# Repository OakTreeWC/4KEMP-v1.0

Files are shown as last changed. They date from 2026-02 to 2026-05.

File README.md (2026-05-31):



# 4KEMP v1.0

### 4 | the number four
### K | k
### E | ey
### M | macro
### P | pad

4KEMP really just a mini macro pad. Nothing special about it. Can be used to play music games and stuff.
This project was made to help my friend learn how to use KiCad and Fusion360, ~~but then became a [hackclub blueprint](https://blueprint.hackclub.com) project for me as well.~~
To use my project, one can use [vial](https://get.vial.today) to change what each key does, and then use it to run functions on their computer.





## Components


## PCB
pcbs are pretty kewl.
also you just lost the game lol.
### Top


### Bottom


## Soldering
I don't have any documentation from when I was actually doing it, but I do have pics of the final product.
### Top
IMG_2629cropped

### Bottom


A lot of my solder joints could be better, it is very inconsistent, and it doesn't look great, but I'm still happy with it.

## Case
I made a few mistakes, and since I neglected to even try to print it at home first, I let them slip, but whatever.

The upper case was 3d printed by JLC 3DP at my own expense in gray resin, which I honestly love the look and feel of. 

However, the lower case is where all the mistakes arose. Stupidity on my part caused these mistakes, but oh well. Because I added neopixels on the bottom and wanted to actually use them, I ordered my lower case in translucent resin. Unfortunately though, I didn't realize that this resin was super vulnerable to warping and had horrible dimensional accuracy. 

When I received the part, I quickly realized how bad it was. Therefore, I attempted to undo the warping with heat and pressure. I ended up pushing it too far though, resulting in a large crack in the base.

Additionally, the poor accuracy caused the top left corner of my macropad to be misaligned. It isn't too bad, but its definitely there.

### Issues

Thin case causing MASSIVE warping.



Attempt to fix warping causing large crack.



Excessive clearance around USB port.



Poor dimensional accuracy of lower case causing horrific misalignment.



## Assembly

Assembly was very straightforward. I first added threaded inserts into my lower case, then put my pcb into the upper case and installed all the switches. After that, I just put the entire upper case/pcb assembly into the lower case, tightened the three M3 bolts, and I was done.





## Bill of Materials
|Item |Description |Qty.|Unit Price (USD)|Total Price  (USD)|URL |Running Total (USD + Tax)|
|---|---|----|---|---|---|---|
|XIAO RP2040 |ARM® Cortex®-M0+ MCU 32-Bit Embedded Evaluation Board |1 |$4.68 |$4.68 |https://www.digikey.com/en/products/detail/seeed-technology-co-ltd/102010428/14672129 |$5.16 |
|Rotary Encoder |Rotary Encoder Incremental 24 Quadrature (Incremental) Horizontal |1 |$1.72 |$1.72 |https://www.digikey.com/en/products/detail/bourns-inc/PEC12R-4020F-S0024/4699271 |$7.06 |
|Reverse Neopixels |Addressable Lighting - 10 LED Discrete Red, Green, Blue (RGB) |1 |$2.95 |$2.95 |https://www.digikey.com/en/products/detail/adafruit-industries-llc/4960/14302512 |$10.31 |
|Backlight Neopixels |Addressable Lighting Neopixel 10 LED Discrete Serial (Shift Register) Red, Green, Blue (RGB) |1 |$4.50 |$4.50 |https://www.digikey.com/en/products/detail/adafruit-industries-llc/1655/5154679 |$15.27 |
|Akko Keyboard Switches|Akko V3 Silver Pro Keyboard Switch 5-Pin Linear Pre-Lubed Switches (45pcs) |1 |$16.99 |$16.99 |https://www.amazon.com/dp/B0CDW6W2P5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 |$34.00 |
|Schottky Diodes |Diode 30 V 200mA Surface Mount 0603 |4 |$0.17 |$0.68 |https://www.digikey.com/en/products/detail/taiwan-semiconductor-corporation/TSS54U-RGG/7360711 |$34.75 |
|Resistor |For Neopixel Data Line. 379 Ohms ±0.1% 0.1W, 1/10W Chip Resistor 0603 (1608 Metric) |1 |$0.12 |$0.12 |https://www.digikey.com/en/products/detail/koa-speer-electronics-inc/RN73R1JTTD3790B25/10016392 |$34.88 |
|PCB |PCB Manufactured by JLCPCB. White, 1.6mm, HASL w/ lead |5 |$0.40 |$2.00 |https://jlcpcb.com |$37.09 |
|Lower Case |Case Manufactured by JLC3DP. 8001 Resin, Translucent |1 |$2.19 |$2.19 |https://jlc3dp.com |$39.50 |
|Upper Case |Case Manufactured by JLCPCB. Black Resin |1 |$2.43 |$2.43 |https://jlc3dp.com |$42.18 |
|Keycaps |DSA Keycaps White 24pcs |1 |$8.99 |$8.99 |www.amazon.com/Mechkeeb-Profile-Switches-Keyboard-Replacement/dp/B0BWDTBF1L |$52.09 |
|Rotary Encoder Knob |Aluminum Rotary Encoder Knob 2pcs |1 |$8.99 |$8.99 |www.amazon.com/Szliyands-Aluminum-Electronic-Potentiometer-Knob，Switch/dp/B099PX52LW |$62.00 |
|Threaded Inserts |M3 Threaded Inserts 152pcs |1 |$6.99 |$6.99 |https://www.amazon.com/Vibit-Threaded-Soldering-Printing-Components/dp/B0FWWW8VP1/ref=sr_1_3 |$69.71 |
|Machine Screws |M3 Screw Kit |1 |$9.99 |$9.99 |https://www.amazon.com/Fgruh-750PCS-Assortment-Washers-Assorted/dp/B0FGV5FCBN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|$80.72 |
|Digikey Shipping | |1 |$4.99 |$4.99 | |$86.22 |
|JLC Shipping | |1 |$8.93 |$8.93 | |$96.07 |

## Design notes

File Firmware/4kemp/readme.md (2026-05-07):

# 4kemp

4kemp

*A short description of the keyboard/project*

* Keyboard Maintainer: [William C.](https://github.com/OakTreeWC)
* Hardware Supported: *The PCBs, controllers supported*
* Hardware Availability: *Links to where you can find this hardware*

Make example for this keyboard (after setting up your build environment):

    make 4kemp:default

Flashing example for this keyboard:

    make 4kemp:default:flash

See the [build environment setup](https://docs.qmk.fm/#/getting_started_build_tools) and the [make instructions](https://docs.qmk.fm/#/getting_started_make_guide) for more information. Brand new to QMK? Start with our [Complete Newbs Guide](https://docs.qmk.fm/#/newbs).

## Bootloader

Enter the bootloader in 3 ways:

* **Bootmagic reset**: Hold down the key at (0,0) in the matrix (usually the top left key or Escape) and plug in the keyboard
* **Physical reset button**: Briefly press the button on the back of the PCB - some may have pads you must short instead
* **Keycode in layout**: Press the key mapped to `QK_BOOT` if it is available

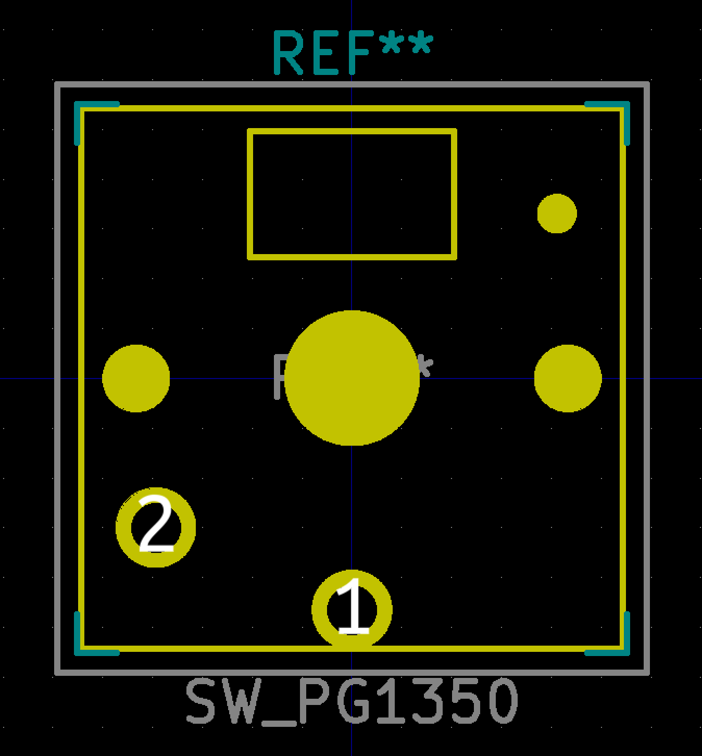
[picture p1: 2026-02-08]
KiCad/CAD Files/keyswitches.pretty-2.1/images/SW_PG1350.png

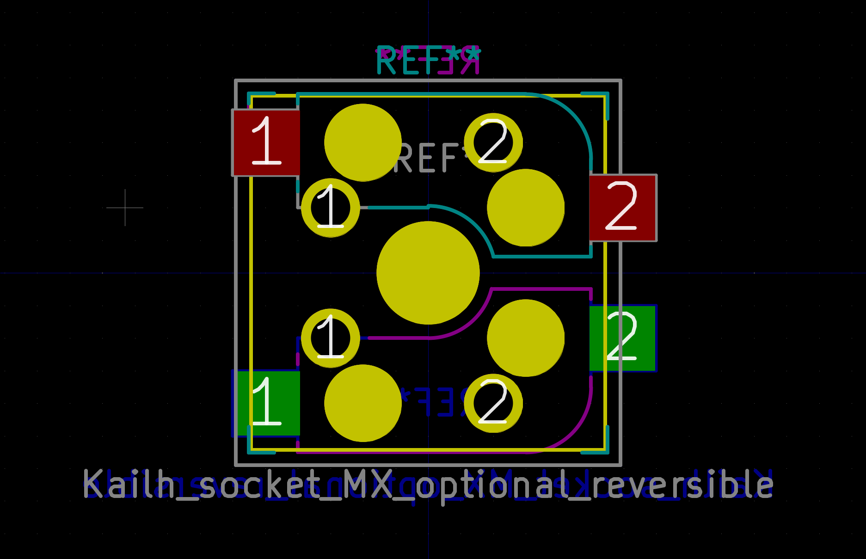
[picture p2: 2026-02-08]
KiCad/CAD Files/keyswitches.pretty-2.1/images/Kailh_socket_MX_optional_reversible_platemount.png

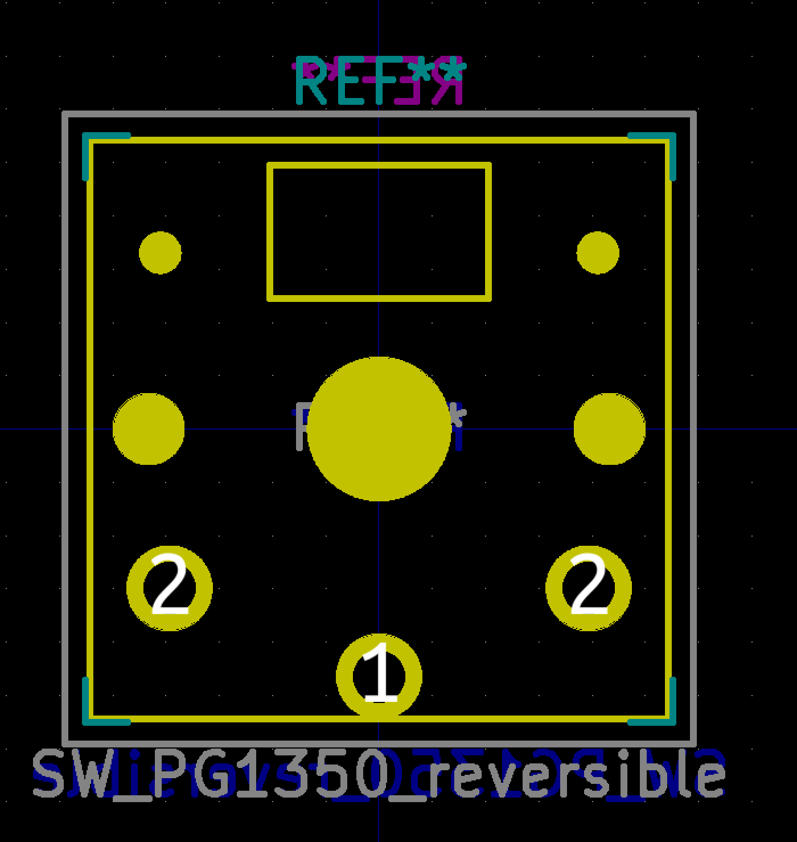
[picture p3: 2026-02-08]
KiCad/CAD Files/keyswitches.pretty-2.1/images/SW_PG1350_reversible.png

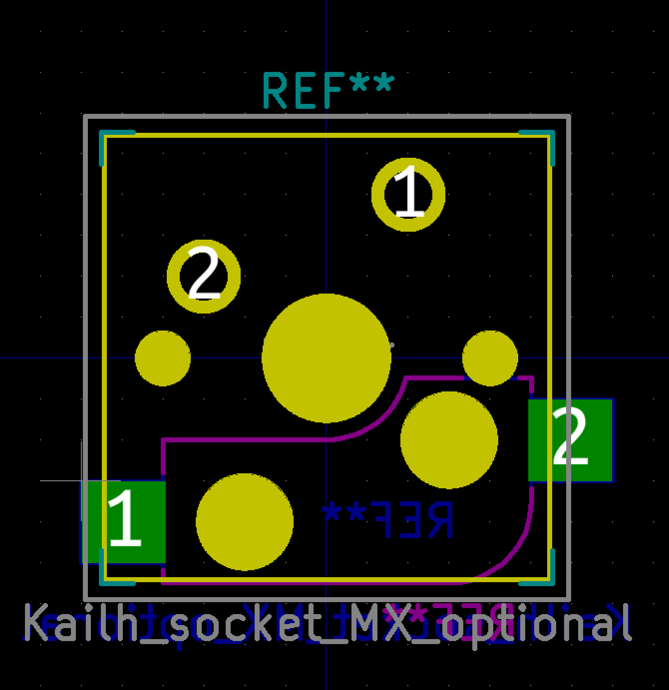
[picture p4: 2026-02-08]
KiCad/CAD Files/keyswitches.pretty-2.1/images/Kailh_socket_MX_optional.png

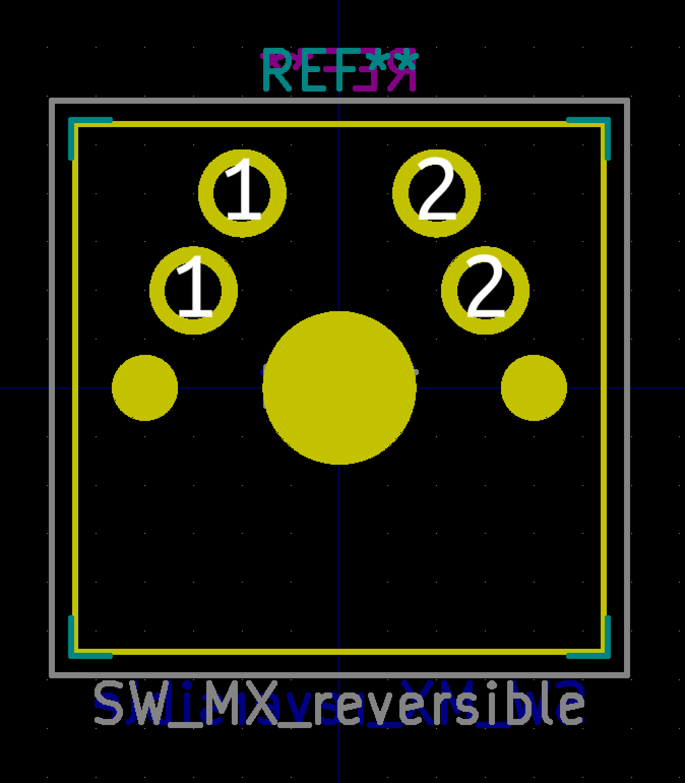
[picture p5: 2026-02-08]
KiCad/CAD Files/keyswitches.pretty-2.1/images/SW_MX_reversible.png

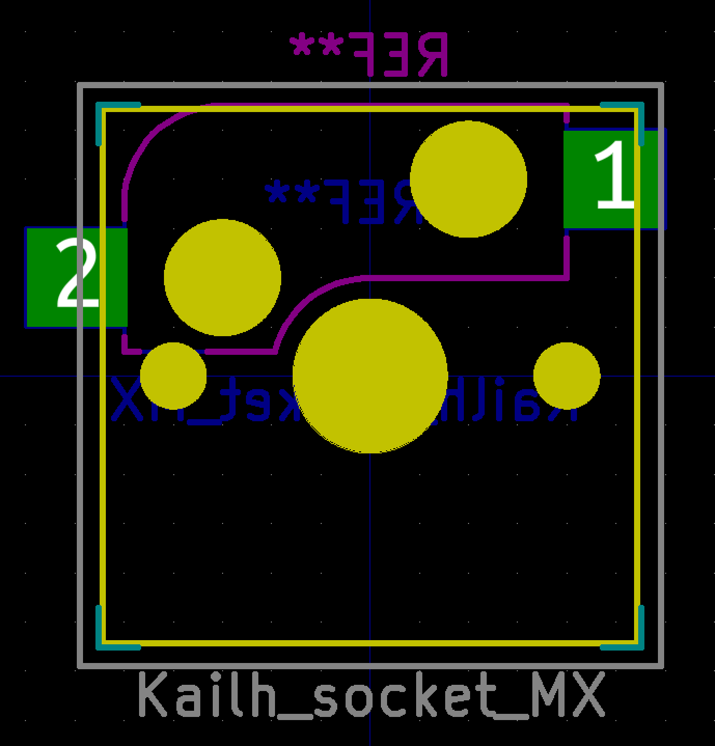
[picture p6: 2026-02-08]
KiCad/CAD Files/keyswitches.pretty-2.1/images/Kailh_socket_MX.png

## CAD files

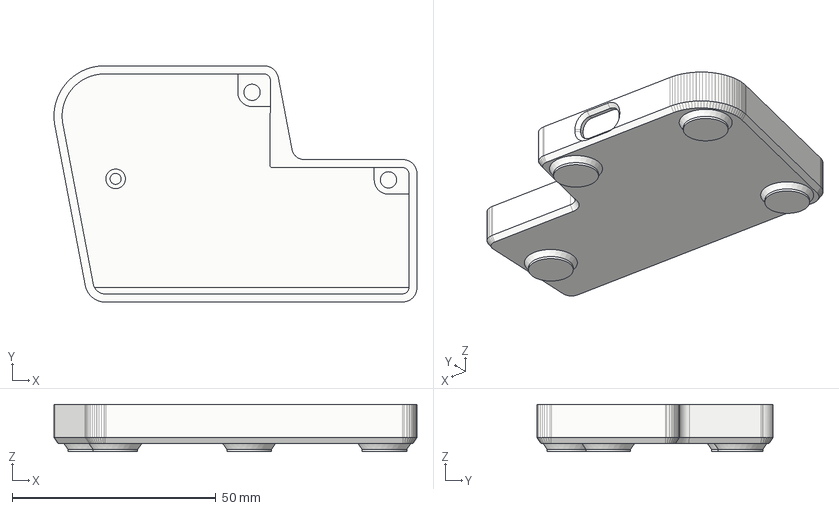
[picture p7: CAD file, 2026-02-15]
Exports/Case Files/4KEMPlowercase.step
89.1 x 58.0 x 11.6 mm

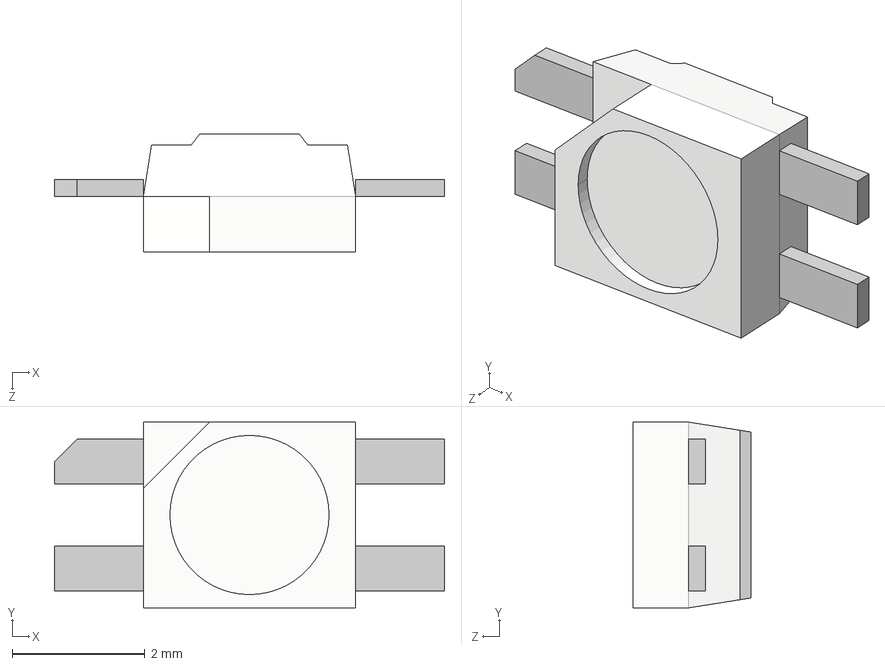
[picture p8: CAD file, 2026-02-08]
KiCad/CAD Files/4960/KiCADv6/4960.stp
5.88 x 2.80 x 1.78 mm

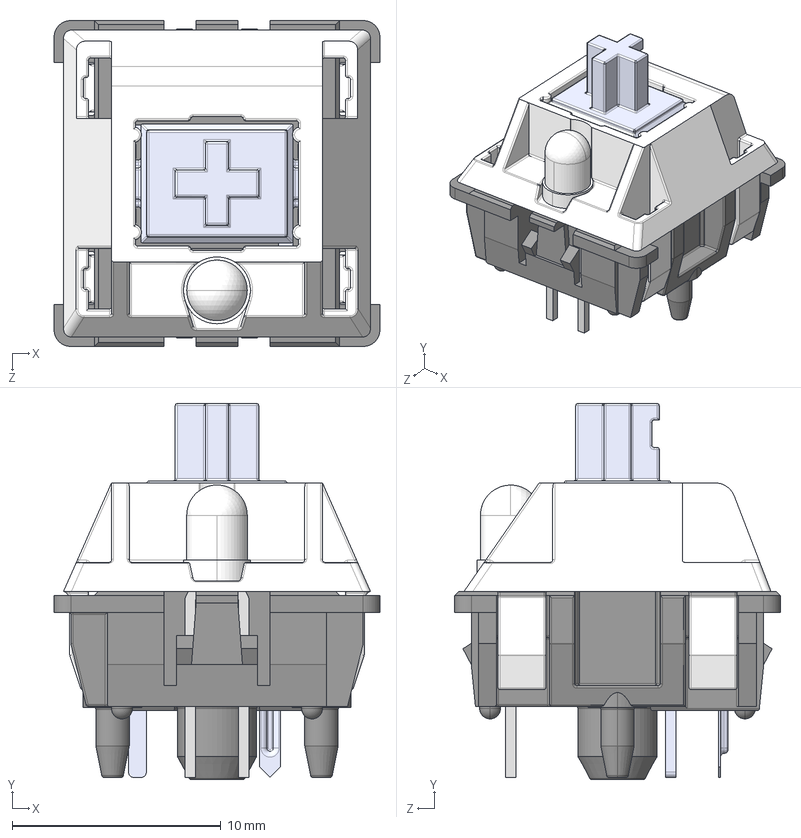
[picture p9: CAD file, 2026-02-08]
KiCad/CAD Files/cherry-mx-red-switch-1.snapshot.3/Cherry MX.STEP
15.6 x 18.0 x 15.6 mm
Bottom
Pulsador
Top
Pieza5^Cherry MX
Pin1
Pin2
Led 3mm_trans

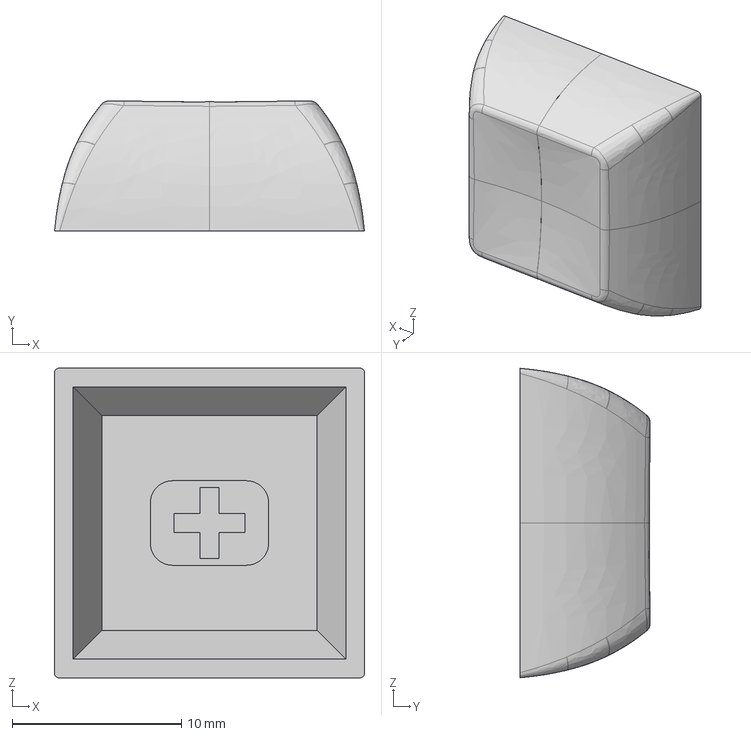
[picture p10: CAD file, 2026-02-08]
KiCad/CAD Files/dsa-keycap-for-cherry-mx-switches-1.snapshot.4/DSA_Keycap_CherryMX.step
18.3 x 7.69 x 18.3 mm

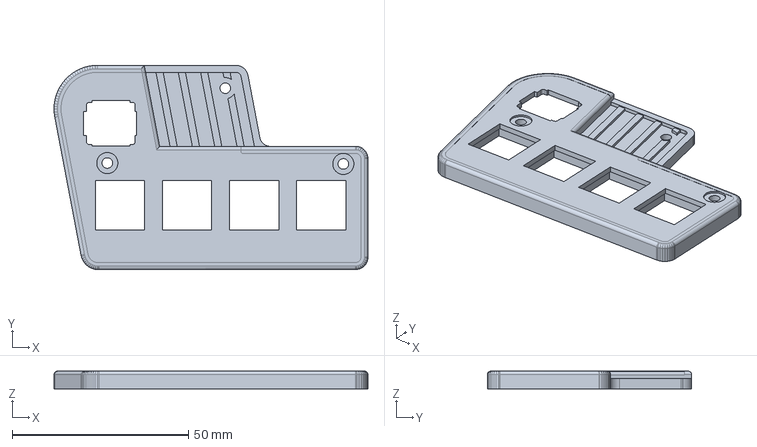
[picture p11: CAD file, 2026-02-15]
Exports/Case Files/4KEMPuppercase.step
89.1 x 58.0 x 5.05 mm

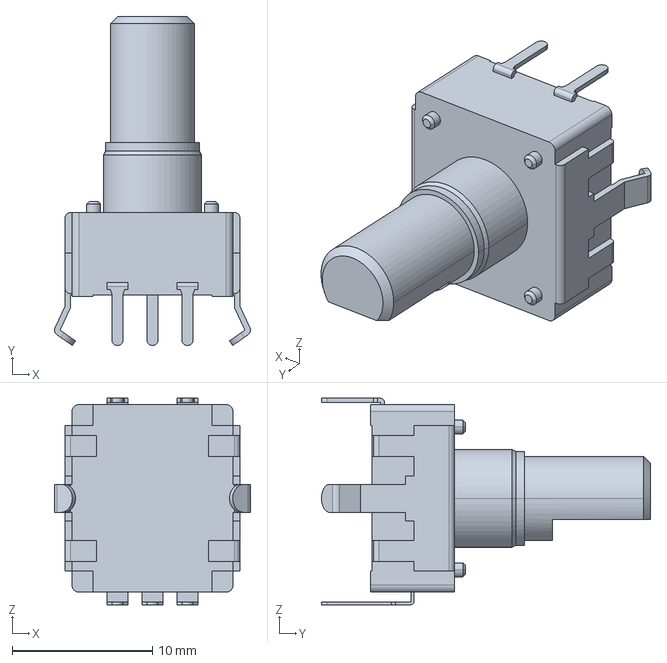
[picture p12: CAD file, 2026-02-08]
KiCad/CAD Files/pec12r-4x20f-sxxxx.step
14.0 x 23.5 x 14.7 mm

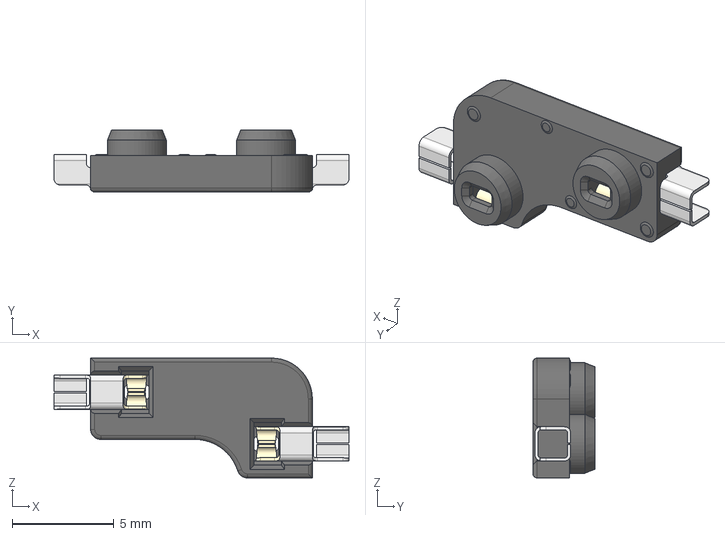
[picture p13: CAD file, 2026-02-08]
KiCad/CAD Files/MX-Hotswap-Socket.step
14.5 x 3.05 x 5.89 mm

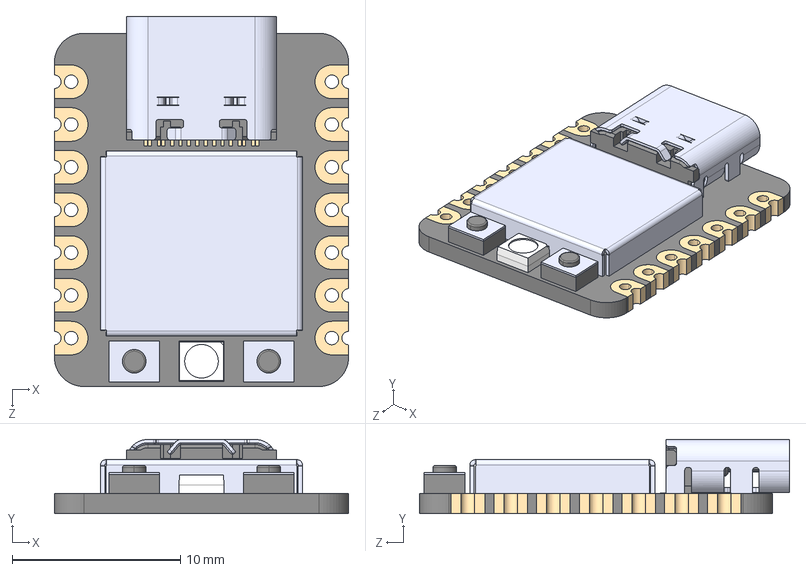
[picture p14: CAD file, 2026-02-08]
KiCad/CAD Files/102010428.step
17.5 x 4.40 x 22.0 mm

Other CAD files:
KiCad/CAD Files/LIB_4960/4960/DEHDL/4960/chips/chips.prt
KiCad/CAD Files/cherry-mx-red-switch-1.snapshot.3/Cherry MX.IGS
KiCad/CAD Files/dsa-keycap-for-cherry-mx-switches-1.snapshot.4/Keycap_adjusted v39.f3d

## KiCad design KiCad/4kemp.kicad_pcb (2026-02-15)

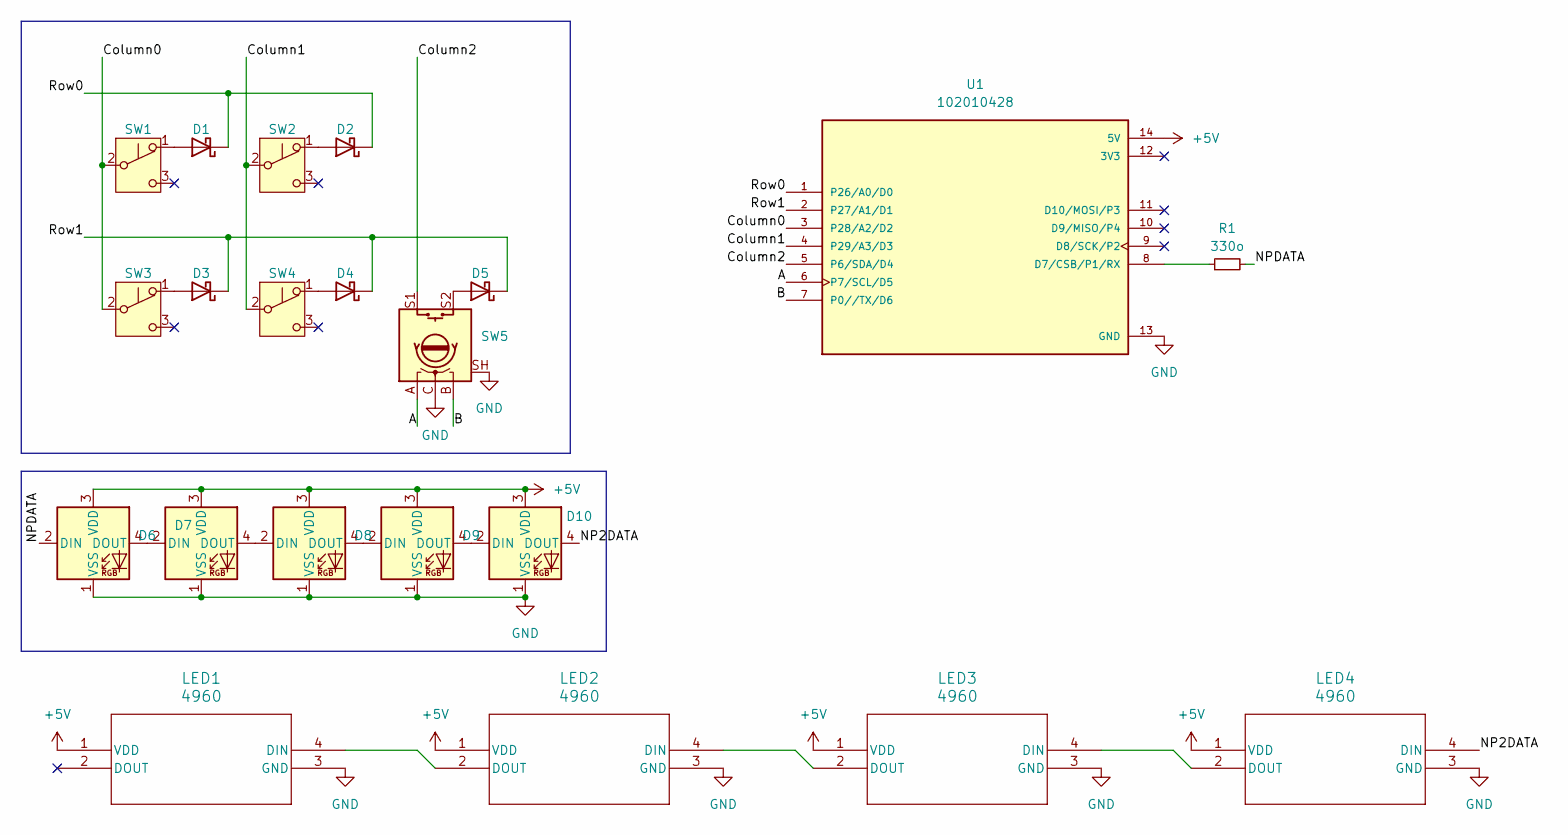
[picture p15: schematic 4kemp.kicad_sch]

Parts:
D1, D2, D3, D4, D5: D_Schottky; D_0603_1608Metric
D6, D7, D8, D9, D10: NeoPixel_THT; LED_SK6812_PLCC4_5.0x5.0mm_P3.2mm
LED1, LED2, LED3, LED4: 4960; 4960_ADA
R1: 330o; R_0603_1608Metric_Pad0.98x0.95mm_HandSolder
SW1, SW2, SW3, SW4: SW_Push_SPDT; Kailh_socket_MX
SW5: RotaryEncoder_Switch; RotaryEncoder_Bourns_Vertical_PEC12R-3x17F-Sxxxx
U1: 102010428; MODULE_102010428; PARTREV 1.3

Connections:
+5V: D6.3 (VDD), D7.3 (VDD), D8.3 (VDD), D9.3 (VDD), D10.3 (VDD), LED1.1 (VDD), LED2.1 (VDD), LED3.1 (VDD), LED4.1 (VDD), U1.14 (5V)
/A: SW5.A, U1.6 (P7/SCL/D5)
/B: SW5.B, U1.7 (P0//TX/D6)
/Column0: SW1.2 (B), SW3.2 (B), U1.3 (P28/A2/D2)
/Column1: SW2.2 (B), SW4.2 (B), U1.4 (P29/A3/D3)
/Column2: SW5.S1, U1.5 (P6/SDA/D4)
/NP2DATA: D10.4 (DOUT), LED4.4 (DIN)
/NPDATA: D6.2 (DIN), R1.2
/Row0: D1.1 (K), D2.1 (K), U1.1 (P26/A0/D0)
/Row1: D3.1 (K), D4.1 (K), D5.1 (K), U1.2 (P27/A1/D1)
GND: D6.1 (VSS), D7.1 (VSS), D8.1 (VSS), D9.1 (VSS), D10.1 (VSS), LED1.3 (GND), LED2.3 (GND), LED3.3 (GND), LED4.3 (GND), SW5.C, SW5.SH (SHIELD), U1.13 (GND)
unnamed: D1.2 (A), SW1.1 (A)
unnamed: D2.2 (A), SW2.1 (A)
unnamed: D3.2 (A), SW3.1 (A)
unnamed: D4.2 (A), SW4.1 (A)
unnamed: D5.2 (A), SW5.S2
unnamed: D6.4 (DOUT), D7.2 (DIN)
unnamed: D7.4 (DOUT), D8.2 (DIN)
unnamed: D8.4 (DOUT), D9.2 (DIN)
unnamed: D9.4 (DOUT), D10.2 (DIN)
unnamed: LED1.4 (DIN), LED2.2 (DOUT)
unnamed: LED2.4 (DIN), LED3.2 (DOUT)
unnamed: LED3.4 (DIN), LED4.2 (DOUT)
unnamed: R1.1, U1.8 (D7/CSB/P1/RX)

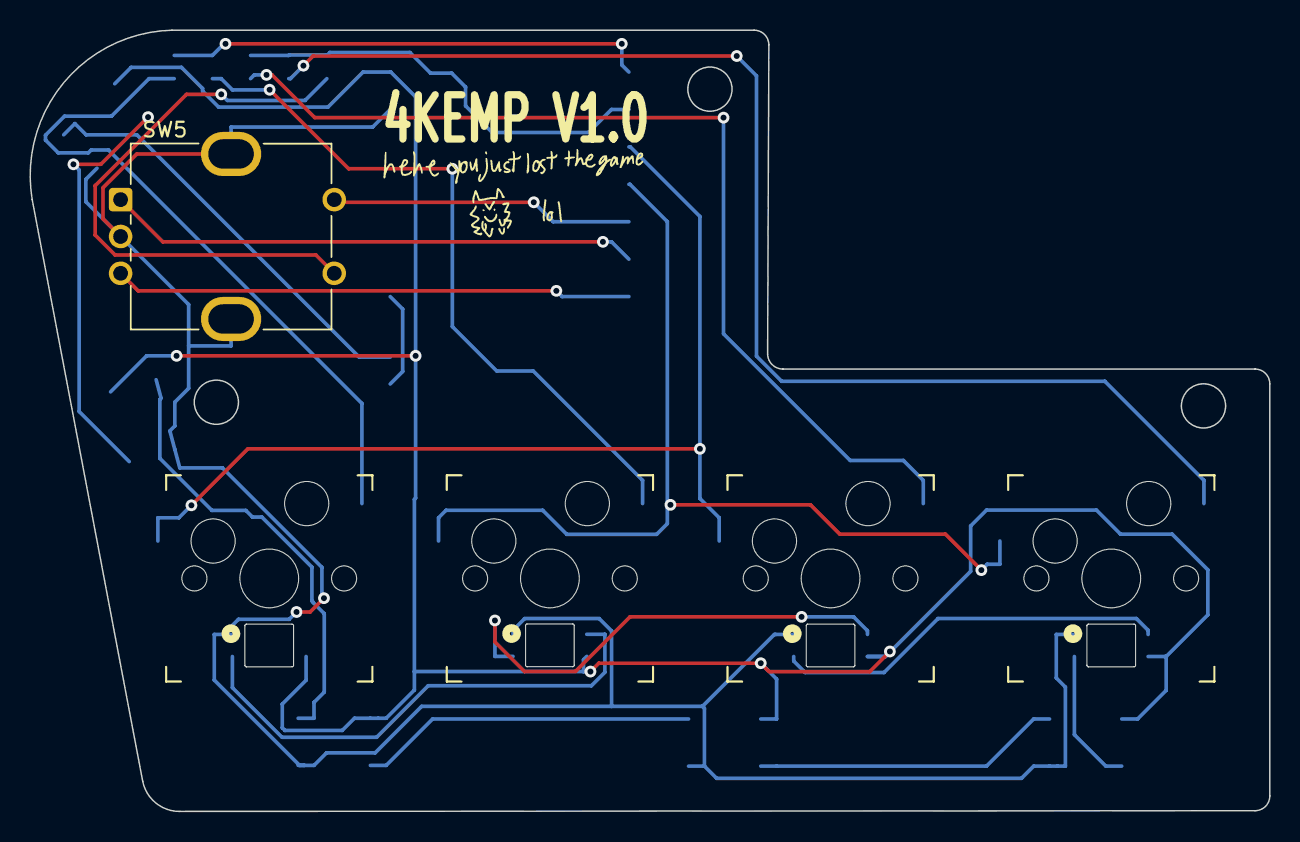
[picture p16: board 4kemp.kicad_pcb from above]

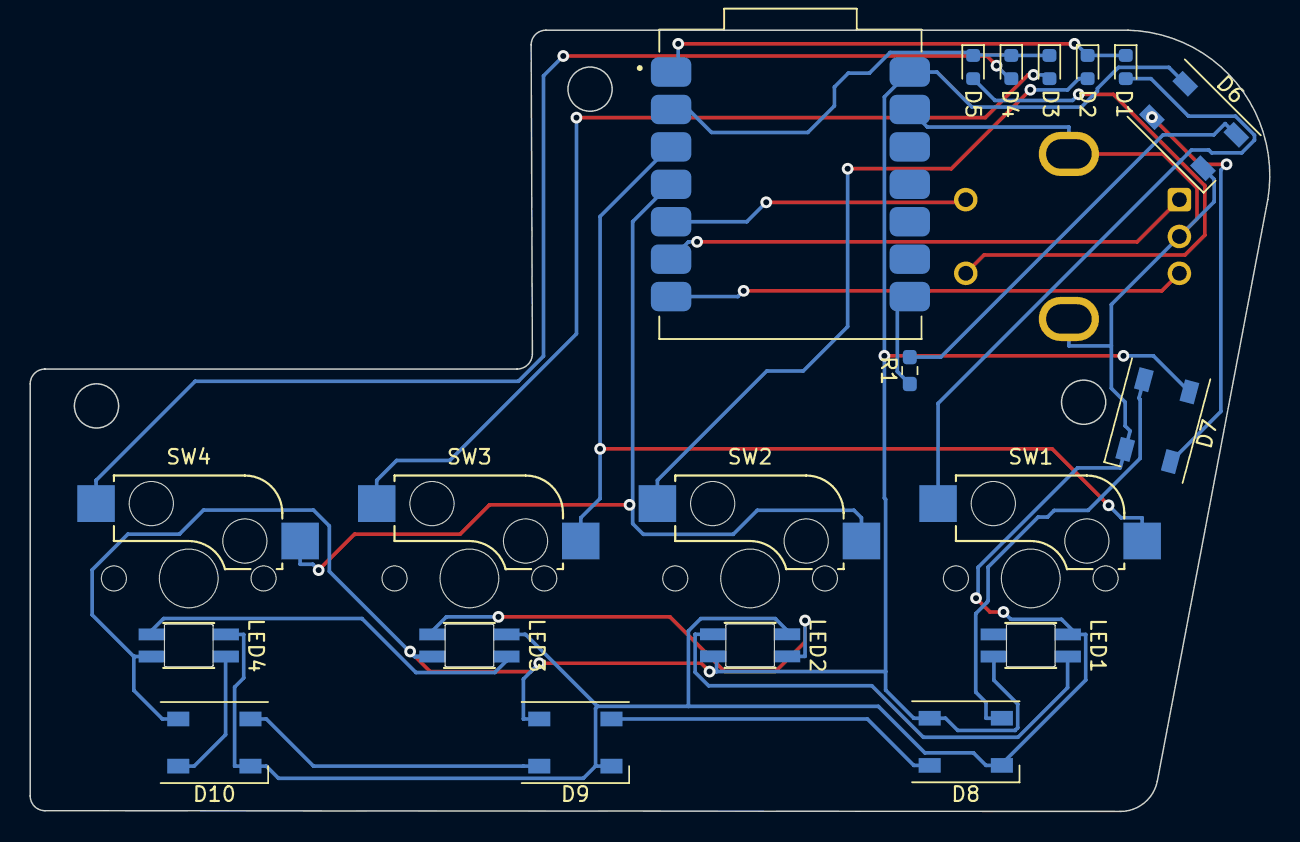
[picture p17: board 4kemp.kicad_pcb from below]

Board: 2 copper layers, 84.1 x 53.0 mm, 21 parts (16 on the bottom side), 24 nets.

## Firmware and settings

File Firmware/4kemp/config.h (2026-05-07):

// Copyright 2026 William C. (@OakTreeWC)
// SPDX-License-Identifier: GPL-2.0-or-later

#pragma once

/*
 * Feature disable options
 *  These options are also useful to firmware size reduction.
 */

/* disable debug print */
//#define NO_DEBUG

/* disable print */
//#define NO_PRINT

/* disable action features */
//#define NO_ACTION_LAYER
//#define NO_ACTION_TAPPING
//#define NO_ACTION_ONESHOT


/* key matrix size */
#define MATRIX_COLS 3
#define MATRIX_ROWS 2

/* key matrix pins */
#define MATRIX_COL_PINS { GP28, GP29, GP6 }
#define MATRIX_ROW_PINS { GP26, GP27 }


#define ENCODERS_PAD_A { GP7 }
#define ENCODERS_PAD_B { GP0 }

/* COL2ROW or ROW2COL */
#define DIODE_DIRECTION COL2ROW

/* Set 0 if debouncing isn't needed */
#define DEBOUNCE 5
#define VIAL_KEYBOARD_UID {0xB7, 0x1A, 0x17, 0x25, 0x78, 0xE3, 0x4A, 0x13}
#define VIAL_UNLOCK_COMBO_ROWS { 0, 1 }
#define VIAL_UNLOCK_COMBO_COLS { 0, 1 }

#define RGB_TRIGGER_ON_KEYDOWN
#define RGB_MATRIX_SLEEP // turn off effects when suspended
#define RGB_MATRIX_LED_COUNT 9

#define WS2812_DI_PIN GP1
#define NOP_FUDGE 1

#define ENABLE_RGB_MATRIX_GRADIENT_LEFT_RIGHT
#define ENABLE_RGB_MATRIX_SPLASH
#define RGBLIGHT_SLEEP
#define RGB_DISABLE_WHEN_USB_SUSPENDED

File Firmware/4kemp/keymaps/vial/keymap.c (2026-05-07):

#include "4kemp.h"
#include "raw_hid.h"
#include "quantum.h"

#define ____ KC_TRNS
const uint16_t PROGMEM keymaps[][MATRIX_ROWS][MATRIX_COLS] = {

    [0] = LAYOUT(
       	____, ____ ,
		____, ____, KC_MPLY
    ),

    [1] = LAYOUT(
        ____, ____,
        ____, ____, ____
    ),

    [2] = LAYOUT(
        ____, ____,
        ____, ____, ____
    ),

    [3] = LAYOUT(
        ____, ____,
        ____, ____, ____
    )
};

#if defined(ENCODER_MAP_ENABLE)
const uint16_t PROGMEM encoder_map[][NUM_ENCODERS][2] = {
    [0] =   { ENCODER_CCW_CW(KC_L, KC_R) },
    [1] =   { ENCODER_CCW_CW(LCTL(KC_F13), LCTL(KC_F14)) },
    [2] =   { ENCODER_CCW_CW(LCTL(KC_F15), LCTL(KC_F16)) },
    [3] =   { ENCODER_CCW_CW(LCTL(KC_F17), LCTL(KC_F18)) }
    //                  Encoder 1
};
#endif


led_config_t g_led_config = { {
  // Key Matrix to LED Index
  {   0,1   },
  {   2,3, NO_LED   }
}, {
  // LED Index to Physical Position
  { 0,  0 }, { 74,  0 },
  {  37,  0 }, {  110,  0 },
  {0,0}, {0,0}, {0,0}, {0,0}, {0,0}
}, {
  // LED Index to Flag
  2,2,2,2,4,4,4,4,4
} };

void changecolor(uint8_t r, uint8_t g, uint8_t b) {
    for (uint8_t i = 0; i < 12; i++) {
        rgb_matrix_set_color(i, r, g, b);
    }
}

void raw_hid_receive_user(uint8_t *data, uint8_t length) {
    if (length < 6) return;           // at least 6 bytes required
    if (data[0] != 0x01) return;      // command 0x01 = set LED

    uint8_t led = data[1];            // LED index (0..3)
    uint8_t r   = data[2];            // red
    uint8_t g   = data[3];            // green
    uint8_t b   = data[4];            // blue

    if (led < 4) {                     // only valid indices
        rgb_matrix_set_color(led, r, g, b);
    }
}

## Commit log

2026-02-08 Made everything
    [102010428.step, 4960.PcbLib, 4960.SchLib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]
2026-02-15 Add Bill of Materials to README
    Added a Bill of Materials section with item details and pricing.
2026-02-15 Fix typo in BOM
    Updated item name in the Bill of Materials section.
2026-02-15 Added 4KEMP.step
    [4KEMP.step]
2026-02-27 Moved KiCad Files to dedicated folder
    [102010428.step, 4960.PcbLib, 4960.SchLib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]
2026-05-31 Expand README with detailed project sections
    Added sections for components, PCB, soldering, case issues, and assembly details.
